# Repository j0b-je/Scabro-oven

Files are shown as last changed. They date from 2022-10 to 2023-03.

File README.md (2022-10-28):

# Scabro-oven
In this repository files relative to the oven project can be found

**The following files can be found here:**
1. The Arduino code for both the slownbox and modified pizza oven
2. The nextion interface files for both the slowbox and modified pizza oven
3. Manuels for both calibrating the thermocoupels and the oven it self(The complete oven manual will be added later on)
4. The electrical diagram of the slowbox and modified pizza oven (Will be added later on) 
5. The following 3D files:
5.1. Modified pizza oven screenholder and casement
5.2. Thermocoupels calibration cube
5.3. The Arduino Mega 2560 holder
5.4 The daughterboard holder for the thermocoupels

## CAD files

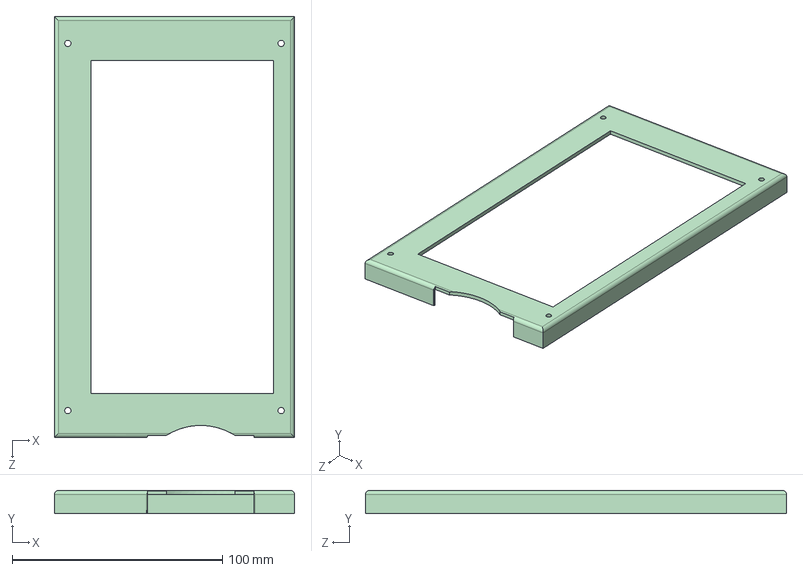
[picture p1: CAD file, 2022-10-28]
5. 3D models/.5.1 Oven screen holder and case/Top part LCD Casement.STEP
114.3 x 11.1 x 200.3 mm

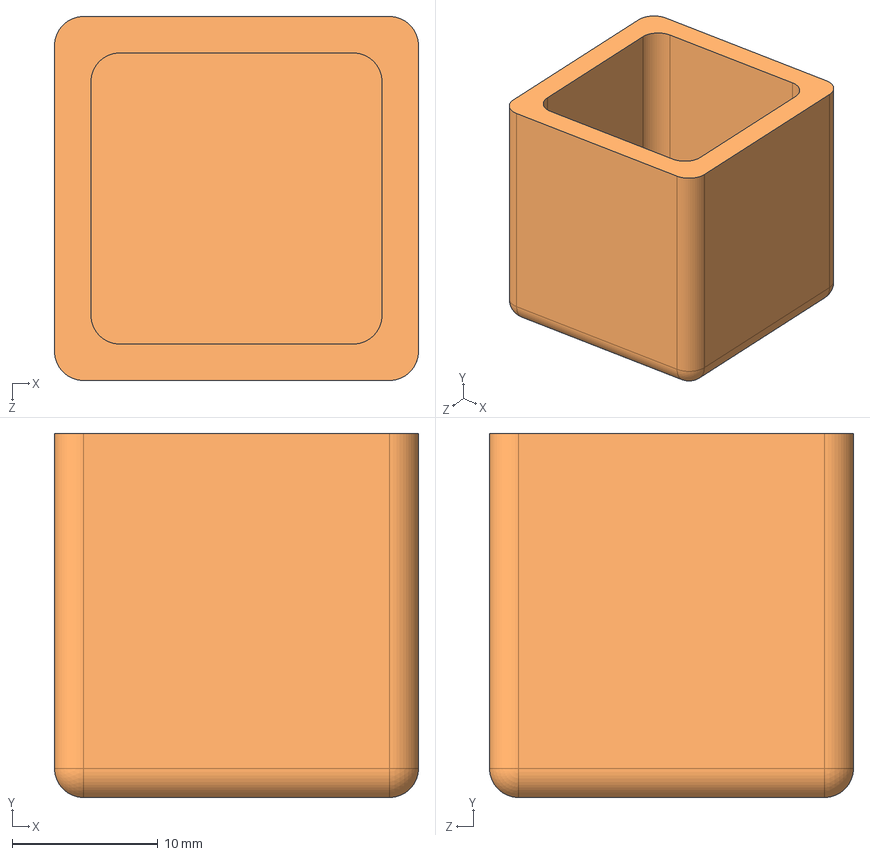
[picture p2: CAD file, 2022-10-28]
5. 3D models/5.2 Thermocouple calibration cube/Calib cube.STEP
25.0 x 25.0 x 25.0 mm

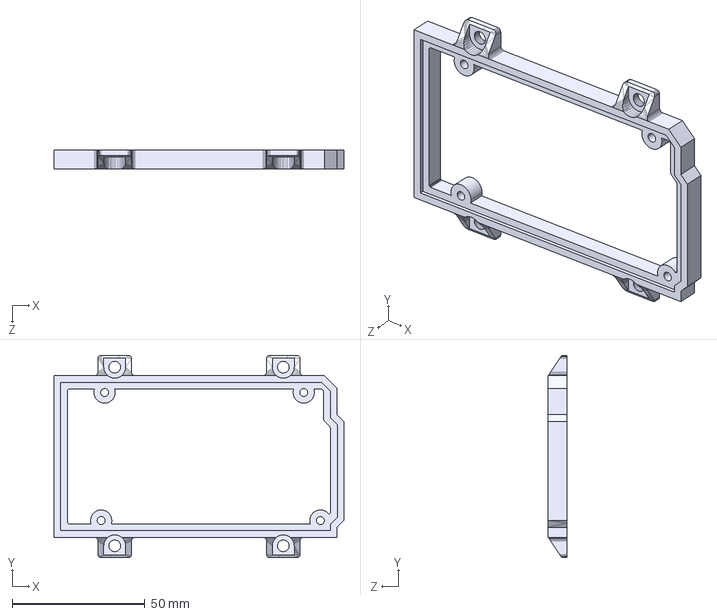
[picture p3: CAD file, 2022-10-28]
5. 3D models/5.3. Arduino Mega 2560 holder/Arduino mega 2560 holder m3.STEP
109.2 x 76.2 x 6.99 mm

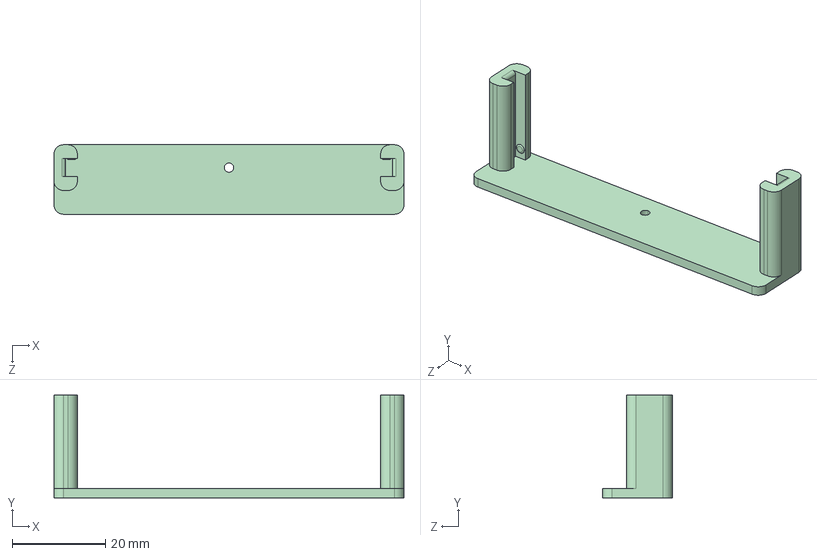
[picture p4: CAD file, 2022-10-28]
5. 3D models/5.4 Daughterboard holder for the thermocouples/Thermocouplers holder.STEP
75.0 x 22.0 x 14.9 mm

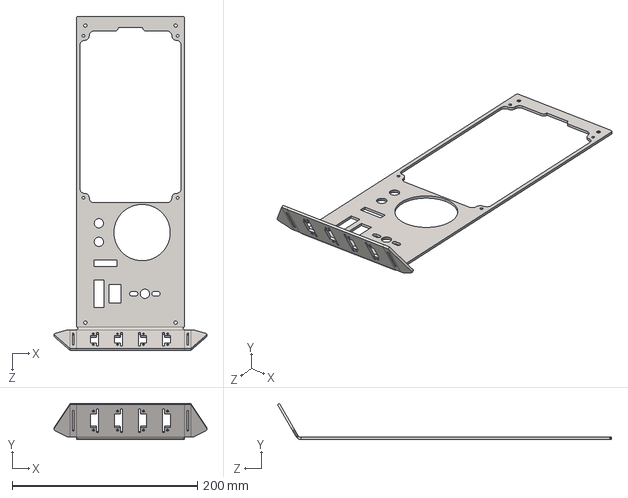
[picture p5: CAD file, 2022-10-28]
5. 3D models/.5.1 Oven screen holder and case/LCD_behuizing V2 sheet metal HandBend .STEP
165.0 x 38.9 x 360.2 mm

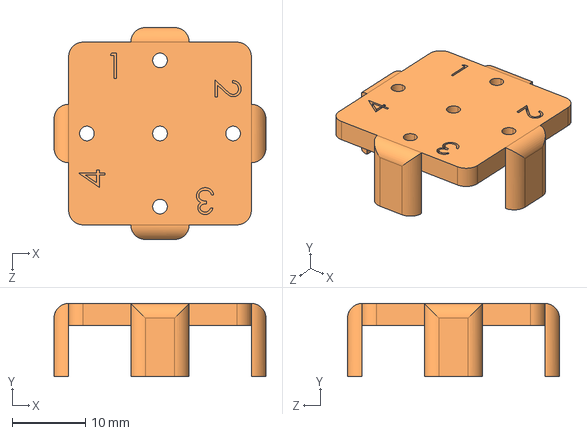
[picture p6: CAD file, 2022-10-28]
5. 3D models/5.2 Thermocouple calibration cube/Calib cube Lid.STEP
29.0 x 10.0 x 29.0 mm

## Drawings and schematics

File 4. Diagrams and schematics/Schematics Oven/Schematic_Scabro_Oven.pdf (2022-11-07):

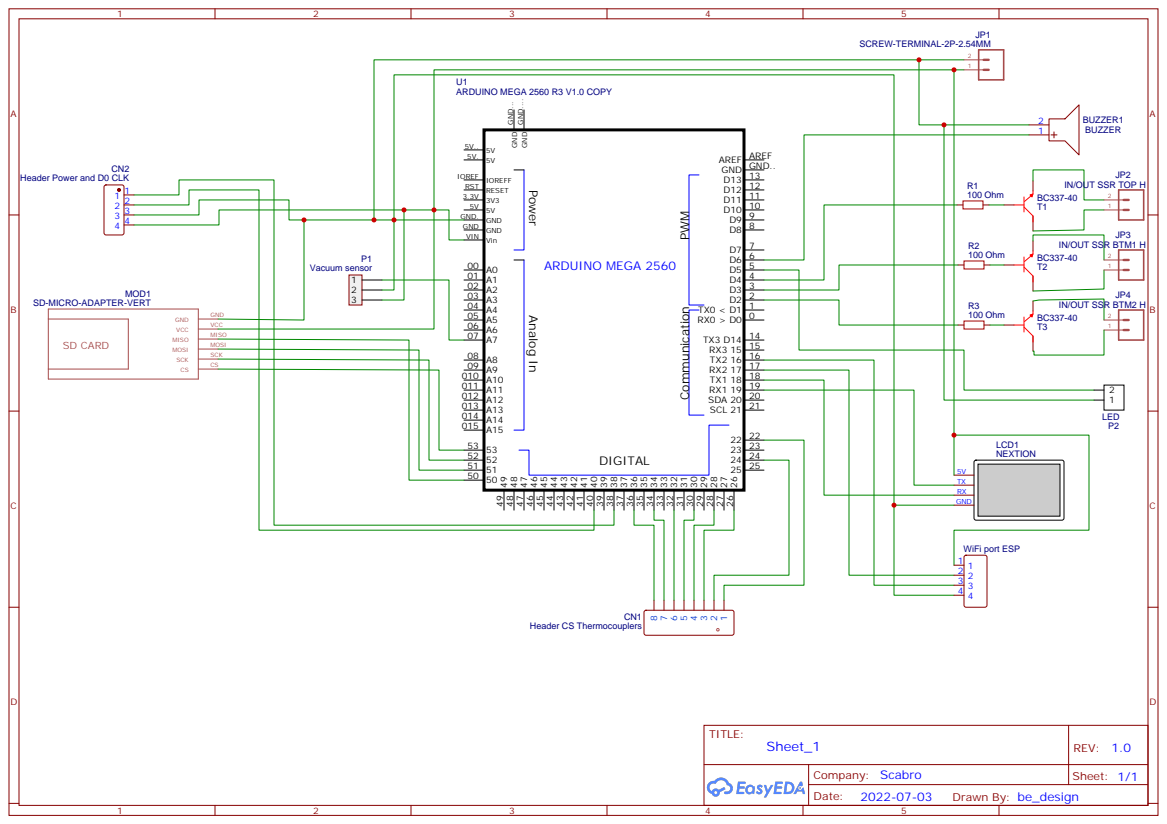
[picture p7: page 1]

Header Power and D0 CLK

SD-MICRO-ADAPTER-VERT

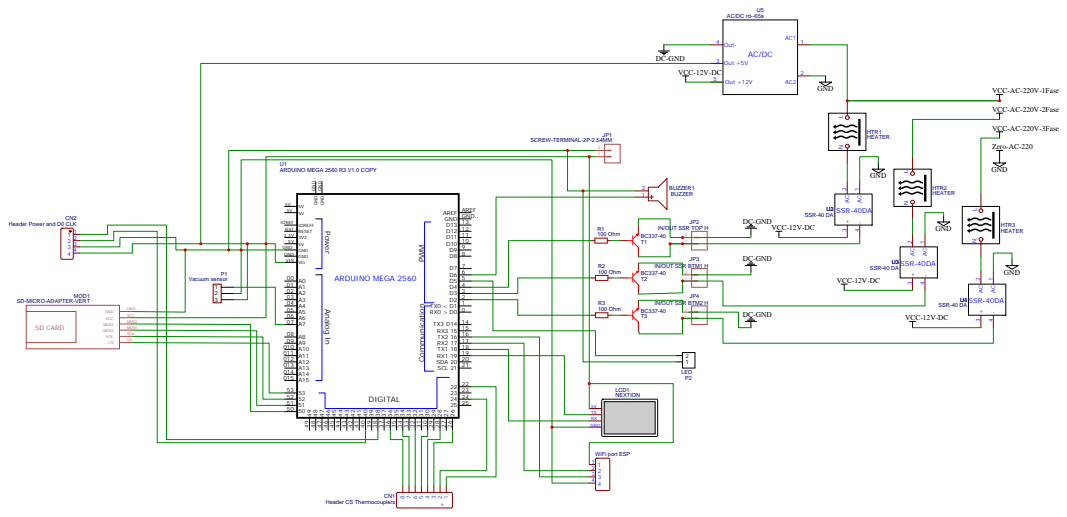
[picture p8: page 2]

Header Power and D0 CLK

SD-MICRO-ADAPTER-VERT

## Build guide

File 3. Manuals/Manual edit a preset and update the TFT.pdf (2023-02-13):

# Change/update the heat cycle presets

- First open the Nextion editor (https://nextion.tech/nextion-editor/)
- Open the HMI file
- Go to the tab on the right side of the screen, “Page”

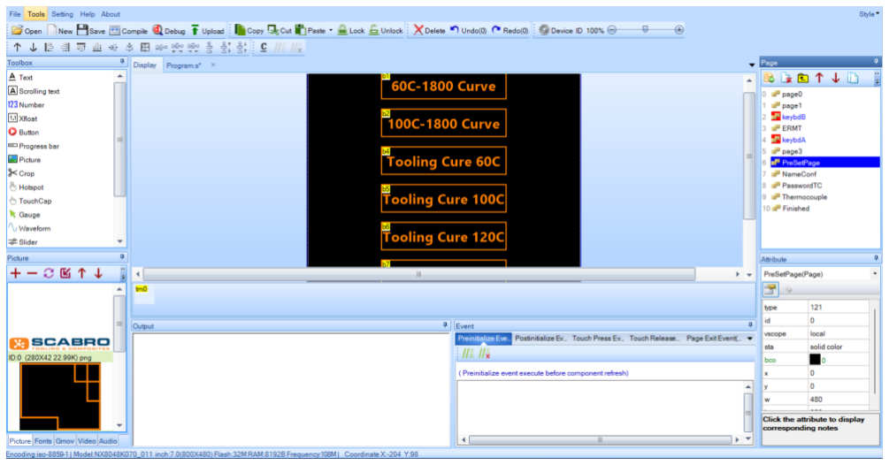
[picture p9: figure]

- Here its possible to edit a preset.

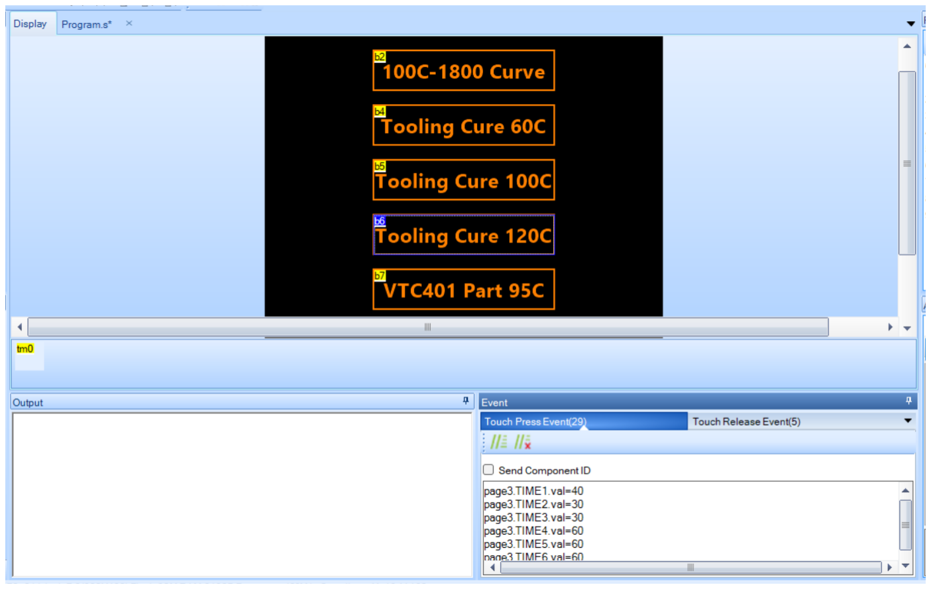
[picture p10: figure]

- In the “Touch Preset Event(X)” it’s possible to edit the time duration and temperature of each stage.

- It’s also possible to change the name of the preset.

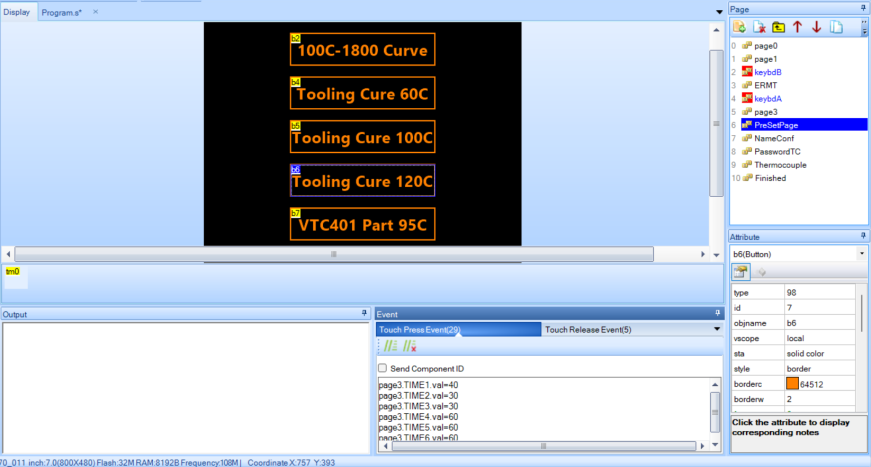
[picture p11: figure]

- Go to the Attributes tab on the right bottom corner.
- Scroll down till “txt” shows up.

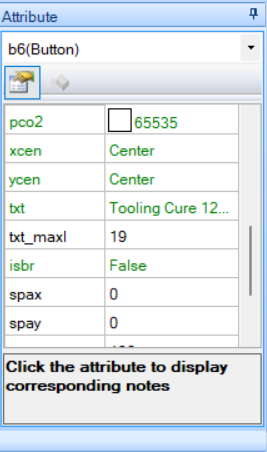
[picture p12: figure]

- By clicking on the text field it’s possible to edit the preset name.
- Under the “txt” field there is also “txt_maxl” this is the maximum amount of characters allowed. This can also be changed by simply increasing or decreasing the number.
- If the name is too long the following will pop up.

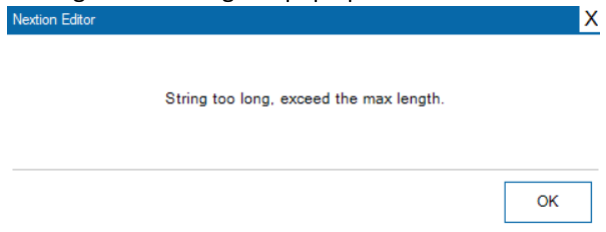
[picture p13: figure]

# Upload the new HMI file to the Nextion

screen.

Materials needed:

- An empty microSD card with less memory than 32GB
- The updated HMI file
- A microSD to USB A adaptor or SD card adaptor, this depends on the computer being used.

Updating the Nextion screen

- Press the compile button to check if there is no error, found on the top toolbar
- If no errors occur go to “File” => “TFT file output” and select the desired folder to save the file to.
- Put the .tft file on the microSD card.
- Remove the microSD card with ONLY the .tft file on it from the computer.
- Turn of the Nextion screen, set the oven switch to 0/off.
- Put the microSD card into the side of the Nextion screen

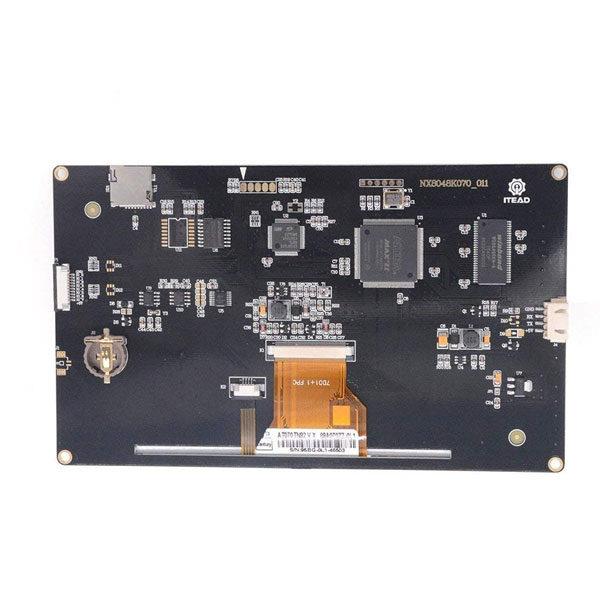
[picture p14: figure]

- Turn on the Nextion screen, it should start installing the new .tft file. Afterward it will start booting the new/edited program.
- After successfully installing the new .tft file turn of the screen and remove the microSD card.

Need more clarification, please use the following guides

- Nextion (https://nextion.tech/faq-items/using-nextion-microsd/)
- Youtube video (https://www.youtube.com/watch?v=6tH-azsptEo)

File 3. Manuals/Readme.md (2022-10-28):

**The complete oven manual will be added later on**

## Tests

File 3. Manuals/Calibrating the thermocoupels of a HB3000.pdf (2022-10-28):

Calibrating the thermocouples of a HB3000

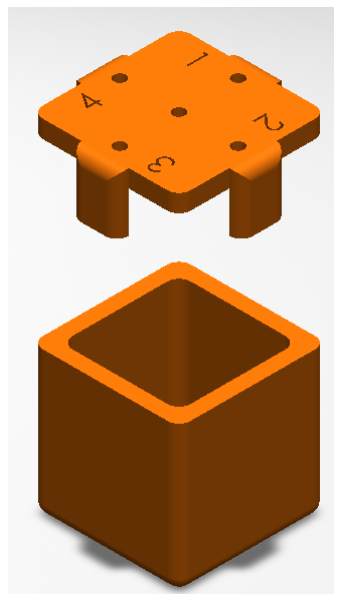
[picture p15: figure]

To calibrate the 4 thermocouple, found on the outside of the furnace successfully the following items are needed:
- Calibration Cube
- 20 CC of water
- A Thermocouple datalogger
- A thermocouple

Start by opening the calibration cube, do this with utmost care because the legs will break if not.
Next, insert the corresponding thermocouples into the holes, followed by the datalogger thermocouple which goes into the centre hole. Make sure that each thermocouple has at least a centimetre of wire on the underside of the lid.
And with the wire all properly seated, the water can be added to the cube.
Let the thermocouple get to the temperature of the water, this will take about a minute. In the meantime, go to the settings page on the screen. Then go to Thermocouples.
First tap “Enter” without anything in text field, this is an extra safety measure. Now the PIN code can be inserted “4123” followed by hitting “Enter” again. Upon opening the screen the value may all be empty, please wait patiently for the oven to represent the values . If this process takes over a minute and still doesn’t show the offset values, use the “Refresh” button.
When the values are loaded in use the “+ “ and “-“ to adjust each of the offsets to the value upon the datalogger. If the thermocouples are adjusted to the corresponding offsets, use the “Back” button to store these and go back to settings page.

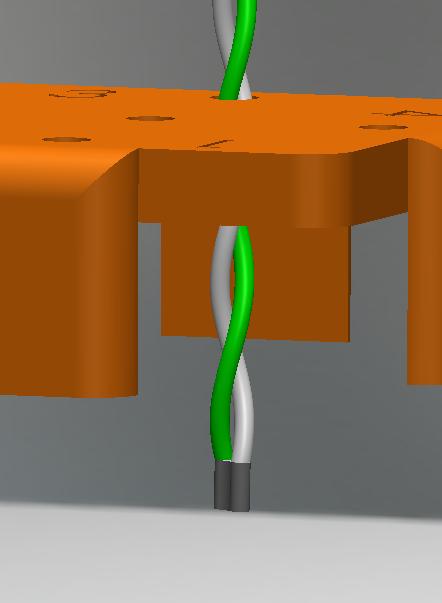
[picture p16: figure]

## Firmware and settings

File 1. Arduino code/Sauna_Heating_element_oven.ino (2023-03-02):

#include "max6675.h"
#include <AutoPID.h>
#include <SPI.h>
#include <SD.h>
#include <EEPROM.h>

#define NextionSerial Serial1
#define DebugSerial Serial

#define OUTPUT_PINHTR1 2
#define OUTPUT_PINHTR2 3
#define OUTPUT_PINHTR3 4

// Eeprom Addresses
// 6 adresses for the thermcouple on the cart 
int TCA1 = 0;
int TCA2 = 2;
int TCA3 = 4;
int TCA4 = 6;
int TCA5 = 8;
int TCA6 = 10;

//Time left intergers
int MAXTemp = 0;
int RampTime = 0;// Will be set after each Speed set
int TotalRampTime = 0;
int TimeSum = 0;

bool TTS = false;

bool Temprecieved = false;
bool Timerecieved = false;

bool FileWithName = false;
bool FileNameCheck = false;

bool TimeLock = false;
bool Dataprocessing = false;
bool ThermoProces = false;

bool SendData = false;

int thermoDO = 38;
int thermoCLK = 40;

//SD card Reader
bool check = false;
File myFile; // create file for writing data to SD Card shield.
const int chipSelect = 4;
char NameType[8];

//thermocouples
int thermoCS = 22;
int thermoCS1 = 24;
int thermoCS2 = 26;
int thermoCS3 = 28;
int thermoCS4 = 30;
int thermoCS5 = 32;
int thermoCS6 = 34;
int thermoCS7 = 36;

//Read Nextion command temp and time
int ReconW = 4;
int FileName = 3;
int TotalChar = 0;

int SetTemp = 0;
unsigned long Time = 0;
int TempHeatUpState = 0;

//Time setting, multiplier
int Minutes = 1;
int MultiplierTime = Minutes * 60;

String readString; //crucial for the decoding of the nextion data
String Name = ""; // string used to save the name of a product, used for the SD card datalog

//time intervals
int T1 = 0;
int T2 = 0;
int T3 = 0;
int T4 = 0;
int T5 = 0;
int T6 = 0;
int T7 = 0;
int T8 = 0;
int T9 = 0;
int T10 = 0;
int T11 = 0;
int T12 = 0;
int T13 = 0;
int T14 = 0;


//Temp intervals
int Temp1 = 0;
int Temp2 = 0;
int Temp3 = 0;
int Temp4 = 0;
int Temp5 = 0;
int Temp6 = 0;
int Temp7 = 0;
int Temp8 = 0;
int Temp9 = 0;
int Temp10 = 0;
int Temp11 = 0;
int Temp12 = 0;
int Temp13 = 0;
int Temp14 = 0;

String CSF;
String NTSF;
String TLF;

//Boolean
boolean TEMPR = false;
boolean TIMR = false;

//Speed setting
int SpeedSet = 1;

//RunningState
int RunningState = 0;
int ThermoCheck = 0;
int Currentstate = 0;

//Delta Time for waiting time heater
unsigned long deltaTime = 0;
unsigned long WriteSDDelta = 0;
unsigned long SendTemp = 0;
unsigned long UpdateThermo = 0;

unsigned long ToTimeLeft = 0;

//Time Left Function
int TimeLeftRun = 0;

MAX6675 thermocouple(thermoCLK, thermoCS, thermoDO);
MAX6675 thermocouple1(thermoCLK, thermoCS1, thermoDO);
MAX6675 thermocouple2(thermoCLK, thermoCS2, thermoDO);
MAX6675 thermocouple3(thermoCLK, thermoCS3, thermoDO);
MAX6675 thermocouple4(thermoCLK, thermoCS4, thermoDO);
MAX6675 thermocouple5(thermoCLK, thermoCS5, thermoDO);
MAX6675 thermocouple6(thermoCLK, thermoCS6, thermoDO);
MAX6675 thermocouple7(thermoCLK, thermoCS7, thermoDO);

const int RunningAverageCount = 8;
float RunningAverageBuffer[RunningAverageCount];
int NextRunningAverage;

// Thermocouple Calibration
int ThermoVal1 = 0;
int ThermoVal2 = 0;
int ThermoVal3 = 0;
int ThermoVal4 = 0;
int ThermoVal5 = 0;
int ThermoVal6 = 0;

#define KP 1.3
#define KI 0.2// was 0,3
#define KD 1

double temperature = 20;
double outputVal = 10;
double bangOn = 6;
double bangOff = 1;
double Setpoint = 0;

//thermocouples corrections
double ThermoCorrection = -7;
double ThermoCorrection1 = -12;

float ThermoCorrection2 = 0;
float ThermoCorrection3 = 0;
float ThermoCorrection4 = 0;
float ThermoCorrection5 = 0;
float ThermoCorrection6 = 0;
float ThermoCorrection7 = 0;

float outputMin = 0;
float outputMax = 80;

//Time left
long TL = 0;

int TimeaddC = 0;
int TAC = 0;

//State Nextion
int NTS = 0;
int CS = 0;

AutoPID myPID(&temperature, &Setpoint, &outputVal, outputMin, outputMax , KP, KI, KD);

String b;

void sendCmd(String cmd)
{
  NextionSerial.print(cmd);
  NextionSerial.write("\xFF\xFF\xFF");
}

void setup()
{

  analogWrite(OUTPUT_PINHTR1, 0);
  analogWrite(OUTPUT_PINHTR2, 0);
  analogWrite(OUTPUT_PINHTR3, 0);

  //Start serial ports
  DebugSerial.begin(9600);
  NextionSerial.begin(115200);

  // Load Thermocouple Offsets form EEPROM including negative values
  ThermoVal1 = (int8_t)EEPROM.read(TCA1);
  ThermoVal2 = (int8_t)EEPROM.read(TCA2);
  ThermoVal3 = (int8_t)EEPROM.read(TCA3);
  ThermoVal4 = (int8_t)EEPROM.read(TCA4);
  ThermoVal5 = (int8_t)EEPROM.read(TCA5);
  ThermoVal6 = (int8_t)EEPROM.read(TCA6);

  ThermoCorrection2 = ThermoVal1 * 0.25;
  ThermoCorrection3 = ThermoVal2 * 0.25;
  ThermoCorrection4 = ThermoVal3 * 0.25;
  ThermoCorrection5 = ThermoVal4 * 0.25;
  ThermoCorrection6 = ThermoVal5 * 0.25;
  ThermoCorrection7 = ThermoVal6 * 0.25;

  DebugSerial.println("OffSet form EEPROM for Thermocouple 2: ");
  DebugSerial.println(ThermoVal1);
  DebugSerial.println(ThermoCorrection2);
  DebugSerial.println("OffSet form EEPROM for Thermocouple 3: ");
  DebugSerial.println(ThermoVal2);
  DebugSerial.println(ThermoCorrection3);
  DebugSerial.println("OffSet form EEPROM for Thermocouple 4: ");
  DebugSerial.println(ThermoVal3);
  DebugSerial.println(ThermoCorrection4);
  DebugSerial.println("OffSet form EEPROM for Thermocouple 5: ");
  DebugSerial.println(ThermoVal4);
  DebugSerial.println(ThermoCorrection5);
  DebugSerial.println("OffSet form EEPROM for Thermocouple 6: ");
  DebugSerial.println(ThermoVal5);
  DebugSerial.println(ThermoCorrection6);
  DebugSerial.println("OffSet form EEPROM for Thermocouple 7: ");
  DebugSerial.println(ThermoVal6);
  DebugSerial.println(ThermoCorrection7);

  //Setup PID Bang Bang
  myPID.setBangBang(bangOn, bangOff);
  //set PID update interval to 250ms
  myPID.setTimeStep(250);

  pinMode(53, OUTPUT); //To check if the micro SD is installed

  DebugSerial.print("Initializing SD card...");

  while (!NextionSerial)
  {
    DebugSerial.println("Waiting on Nextion Screen");
  }

  sendCmd("ArduinoV.txt = \"Blue Mosque\"");
  DebugSerial.println("Sending start up to Nextion Screen");
  delay(500);
  sendCmd("Trigger.val=1");
  sendCmd(""); // clear the buffer
  sendCmd("LiveTemp.txt=\"Initializing\"");
  sendCmd(""); // clear the buffer
  delay(100);

  DebugSerial.println("Awaiting Command of the Nextion Screen or DebugSerial");

  //Nextion recieve data Temp and Time
  TotalChar = ReconW + FileName;
  if (SD.begin())
  {
    DebugSerial.println("SD card is ready to use.");
    sendCmd("page1.SDcardState.txt=\"SD card istalled\"");
  }
  else
  {
    DebugSerial.println("SD card initialization failed");
    sendCmd("page1.SDcardState.txt = \"No SD card istalled\"");
    FileNameCheck = true;
  }

}
void loop()
{
  unsigned long currentMillis = millis();//Start Timer

  String mytext;
  String myvalue;
  String TempvalueAVR;
  String Tempvalue;
  String Tempvalue1;
  String Tempvalue2;
  String Tempvalue3;
  String Tempvalue4;
  String Tempvalue5;
  String Tempvalue6;
  String Tempvalue7;
  String Tempvalue8;

  String Tempval2;
  String Tempval3;
  String Tempval4;
  String Tempval5;
  String Tempval6;
  String Tempval7;

  String TL;
  String NTS;
  String CS;
  String message;
  String Processstate;

  // Thermocouple offset
  String TempOffSet1;
  String TempOffSet2;
  String TempOffSet3;
  String TempOffSet4;
  String TempOffSet5;
  String TempOffSet6;

  String OffSetN1;
  String OffSetN2;
  String OffSetN3;
  String OffSetN4;
  String OffSetN5;
  String OffSetN6;

  String THC2;
  String THC3;
  String THC4;
  String THC5;
  String THC6;
  String THC7;

  if (NextionSerial.available() > 0) {

    if (Dataprocessing == false) {
      DebugSerial.print("Dataproccesing state is: ");
      DebugSerial.println(Dataprocessing);
      DebugSerial.print("FileNameCheck state is: ");
      DebugSerial.println(FileNameCheck);
    }
    /*  DebugSerial.println("OffSet form EEPROM for Thermocouples: ");
      DebugSerial.println(ThermoCorrection4);
      DebugSerial.println(ThermoCorrection5);
      DebugSerial.println(ThermoCorrection6);
      DebugSerial.println(ThermoCorrection7); */

    DebugSerial.println("Incoming Data form nextion: ");
    DebugSerial.println(readString);

    if (Dataprocessing == true && ThermoProces == false) {
      sendCmd("t16.txt=\"Processing Data\"");
    }

    char c = NextionSerial.read();  //gets one byte from serial buffer

    if (c == '.') {
      if ('Z') {
        DebugSerial.println("Start Thermocouple Calibration process");
        ThermoProces = true;
        DebugSerial.print("Thermoproces state: ");
        DebugSerial.println(ThermoProces);
      }
    }

    if (c == '$') {
      String Trash = readString;
      DebugSerial.print("The recieved Trash: ");
      DebugSerial.println(Trash);
      Trash = "";

      //if (NextionSerial.available() == 0)//

      DebugSerial.println("Nextion Serial Buffer is empty");
      sendCmd("SendTime.val=1");
      sendCmd("t16.txt=\"Recieved Data\"");
      Dataprocessing = true;

      readString += c; //makes the string readString
    }

    if (c == '!') {
      String Trash = readString;
      DebugSerial.print("The recieved Trash: ");
      DebugSerial.println(Trash);
      Trash = "";
      readString = ""; //clears variable for new input
    }

    if (c == 'x') {
      DebugSerial.println("No File Name has been given");
      FileNameCheck = true;
      //Dataprocessing = false;
      //sendCmd("StopSender.val=0");
      readString = ""; //clears variable for new input
    }

    if (c == '>') { //Not using fro the new communication, used for hand shake methode -> Force data all the time
      DebugSerial.println("Recieved Nexttion Data request");
      SendData = true;
      readString = ""; //clears variable for new input
    }

    if (c == '(') {
      FileWithName = false;
      DebugSerial.print("The up comming Run doesn't require a file name ");
    }

    if (c == ')') {
      FileWithName = true;
      DebugSerial.print("The up comming Run requires a File Name: ");
      DebugSerial.print(FileWithName);
    }

    if (c == '@') {
      sendCmd("StopSender.val=0"); //Send to Nextion the running state
      DebugSerial.println("A Stop command has been isued");
      sendCmd("RunningState.txt=\"Stop\""); //Send to Nextion the running state

      readString = ""; //clears variable for new input
      if (check == true) {
        myFile.println("Programm Has been stopped");
        myFile.close(); // if There is a file open it will close it
        readString = ""; //clears variable for new input
        check = false;
      }
      sendCmd("t16.txt=\" \"");
      TempHeatUpState = 15; //Stop command
    }

    if (c == ',') {
      Dataprocessing = true;
      while (readString.length() > 1) {
        DebugSerial.print("The Following Data will be processed: ");
        DebugSerial.println(readString); //prints string to serial port out
        int n = readString.toInt();  //convert readString into a number
        DebugSerial.print("Writing Recieved data: ");
        DebugSerial.println(n);
        if (TimeLock == false); {
          if (readString.indexOf('a') > 0) T1 = n;
          if (readString.indexOf('b') > 0) T2 = n;
          if (readString.indexOf('c') > 0) T3 = n;
          if (readString.indexOf('d') > 0) T4 = n;
          if (readString.indexOf('e') > 0) T5 = n;
          if (readString.indexOf('f') > 0) T6 = n;
          if (readString.indexOf('g') > 0) T7 = n;
          if (readString.indexOf('h') > 0) T8 = n;
          if (readString.indexOf('i') > 0) T9 = n;
          if (readString.indexOf('j') > 0) T10 = n;
          if (readString.indexOf('k') > 0) T11 = n;
          if (readString.indexOf('l') > 0) T12 = n;
          if (readString.indexOf('m') > 0) T13 = n;
          if (readString.indexOf('n') > 0) T14 = n;
          if (readString.indexOf('o') > 0) {
            Timerecieved = true;
            sendCmd("SendT.val=1");
            sendCmd("SendTime.val=0");
            TimeLock = false;
          }
        }
        if (readString.indexOf('A') > 0) Temp1 = n;
        if (readString.indexOf('B') > 0) Temp2 = n;
        if (readString.indexOf('C') > 0) Temp3 = n;
        if (readString.indexOf('D') > 0) Temp4 = n;
        if (readString.indexOf('E') > 0) Temp5 = n;
        if (readString.indexOf('F') > 0) Temp6 = n;
        if (readString.indexOf('G') > 0) Temp7 = n;
        if (readString.indexOf('H') > 0) Temp8 = n;
        if (readString.indexOf('I') > 0) Temp9 = n;
        if (readString.indexOf('J') > 0) Temp10 = n;
        if (readString.indexOf('K') > 0) Temp11 = n;
        if (readString.indexOf('L') > 0) Temp12 = n;
        if (readString.indexOf('M') > 0) Temp13 = n;
        if (readString.indexOf('N') > 0) Temp14 = n;
        if (readString.indexOf('O') > 0) {
          Temprecieved = true;
          sendCmd("vis b5,1");
          sendCmd("t16.txt=\" \"");
          Dataprocessing = false;
          sendCmd("StopSend.val=0");
        }

        if (readString.indexOf(':') > 0) {
          SpeedSet = n;
          DebugSerial.print("SpeedSet: ");
          DebugSerial.println(SpeedSet);
          Dataprocessing = false;
        }

        if (readString.indexOf('#') > 0 && FileWithName == true) {
          if (readString.indexOf('#')) Name = readString;
          DebugSerial.print("The recieved name is: ");
          DebugSerial.println(Name);
          int LastIndex = Name.length() - 1;
          Name.remove(LastIndex);
          Name.concat(".TXT");
          DebugSerial.println(Name);

          Name.toCharArray(NameType, Name.length() + 1);
          if (SD.exists(Name)) {// Checking if The Name of the File is already occupied
            sendCmd("page NameConf"); // Opens error page on Nextion
            DebugSerial.println("File name exists.");
            FileNameCheck = false;
          }

          else {
            DebugSerial.println("File name doesn't exist.");
            DebugSerial.println(NameType);
            myFile = SD.open(Name, FILE_WRITE);
            myFile.print("This file originatie from this file name: ");
            myFile.println(Name);

            FileNameCheck = true;
            check = true;

            readString = ""; //clears variable for new input
          }

          Dataprocessing = false;
        }
        readString = ""; //clears variable for new input
      }
    }
    else {
      readString += c; //makes the string readString
    }
  }

  while (ThermoProces == true && Dataprocessing == false) {

    char c = NextionSerial.read();

    //TempOffSet1 = int(thermocouple4.readCelsius() - ThermoCorrection4);

    TempOffSet1 = int(thermocouple2.readCelsius() + ThermoCorrection2);
    TempOffSet2 = int(thermocouple3.readCelsius() + ThermoCorrection3);
    TempOffSet3 = int(thermocouple4.readCelsius() + ThermoCorrection4);
    TempOffSet4 = int(thermocouple5.readCelsius() + ThermoCorrection5);
    TempOffSet5 = int(thermocouple6.readCelsius() + ThermoCorrection6);
    TempOffSet6 = int(thermocouple7.readCelsius() + ThermoCorrection7);

    THC2 = ThermoVal1 * 0.25;
    THC3 = ThermoVal2 * 0.25;
    THC4 = ThermoVal3 * 0.25;
    THC5 = ThermoVal4 * 0.25;
    THC6 = ThermoVal5 * 0.25;
    THC7 = ThermoVal6 * 0.25;
    
    OffSetN1 = "\"" + THC2 + "\"";
    OffSetN2 = "\"" + THC3 + "\"";
    OffSetN3 = "\"" + THC4 + "\"";
    OffSetN4 = "\"" + THC5 + "\"";
    OffSetN5 = "\"" + THC6 + "\"";
    OffSetN6 = "\"" + THC7 + "\"";

    // current temperature with compensation

    sendCmd("OffSet1.txt=" + OffSetN1);
    sendCmd("OffSet2.txt=" + OffSetN2);
    sendCmd("OffSet3.txt=" + OffSetN3);
    sendCmd("OffSet4.txt=" + OffSetN4);
    sendCmd("OffSet5.txt=" + OffSetN5);
    sendCmd("OffSet6.txt=" + OffSetN6);
    
    sendCmd("THCC1.val=" + TempOffSet1);
    sendCmd("THCC2.val=" + TempOffSet2);
    sendCmd("THCC3.val=" + TempOffSet3);
    sendCmd("THCC4.val=" + TempOffSet4);
    sendCmd("THCC5.val=" + TempOffSet5);
    sendCmd("THCC6.val=" + TempOffSet6);

    if (c == 'A') {
      ThermoVal1 ++;
      DebugSerial.println("Increasing First Thermocouple");
      ThermoCorrection2 = ThermoVal1 * 0.25;
      sendCmd("OffSet1.txt=" + OffSetN1);
    }
    if (c == 'a') {
      ThermoVal1 --;
      DebugSerial.println("Decreasing First Thermocouple");
      ThermoCorrection2 = ThermoVal1 * 0.25;
      sendCmd("OffSet1.txt=" + OffSetN1);
    }
    if (c == 'B') {
      ThermoVal2 ++;
      DebugSerial.println("Increasing Second Thermocouple");
      ThermoCorrection3 = ThermoVal2 * 0.25;
      sendCmd("OffSet2.txt=" + OffSetN2);
    }
    if (c == 'b') {
      ThermoVal2 --;
      DebugSerial.println("Decreasing Second Thermocouple");
      ThermoCorrection3 = ThermoVal2 * 0.25;
      sendCmd("OffSet2.txt=" + OffSetN2);
    }
    if (c == 'C') {
      ThermoVal3 ++;
      DebugSerial.println("Increasing Third Thermocouple");
      ThermoCorrection4 = ThermoVal3 * 0.25;
      sendCmd("OffSet3.txt=" + OffSetN3);
    }
    if (c == 'c') {
      ThermoVal3 --;
      DebugSerial.println("Decreasing Third Thermocouple");
      ThermoCorrection4 = ThermoVal3 * 0.25;
      sendCmd("OffSet3.txt=" + OffSetN3);
    }
    if (c == 'D') {
      ThermoVal4 ++;
      DebugSerial.println("Increasing Fourth Thermocouple");
      ThermoCorrection5 = ThermoVal4 * 0.25;
      sendCmd("OffSet4.txt=" + OffSetN4);
    }
    if (c == 'd') {
      ThermoVal4 --;
      DebugSerial.println("Decreasing Fourth Thermocouple");
      ThermoCorrection5 = ThermoVal4 * 0.25;
      sendCmd("OffSet4.txt=" + OffSetN4);
    }
    
    if (c == 'E') {
      ThermoVal5 ++;
      DebugSerial.println("Increasing Fifth Thermocouple");
      ThermoCorrection6 = ThermoVal5 * 0.25;
      sendCmd("OffSet5.txt=" + OffSetN5);
    }
    if (c == 'e') {
      ThermoVal5 --;
      DebugSerial.println("Decreasing Fifth Thermocouple");
      ThermoCorrection6 = ThermoVal5 * 0.25;
      sendCmd("OffSet5.txt=" + OffSetN5);
    }

     if (c == 'F') {
      ThermoVal6 ++;
      DebugSerial.println("Increasing Sixth Thermocouple");
      ThermoCorrection7 = ThermoVal6 * 0.25;
      sendCmd("OffSet6.txt=" + OffSetN6);
    }
    if (c == 'f') {
      ThermoVal6 --;
      DebugSerial.println("Decreasing Sixth Thermocouple");
      ThermoCorrection7 = ThermoVal6 * 0.25;
      sendCmd("OffSet6.txt=" + OffSetN6);
    }
      
    // Back button
    if (c == 'X') {
      DebugSerial.println("Back Button has been pressed");

      EEPROM.update(TCA1, ThermoVal1);
      EEPROM.update(TCA2, ThermoVal2);
      EEPROM.update(TCA3, ThermoVal3);
      EEPROM.update(TCA4, ThermoVal4);
      EEPROM.update(TCA5, ThermoVal5);
      EEPROM.update(TCA6, ThermoVal6);

      DebugSerial.println("Data Has been Saved in the EEPROM");
      ThermoProces = false;
      return;
    }

    readString = ""; //clears variable for new input
  }

  if (Dataprocessing == false && ThermoProces == false) {

    if (Timerecieved == true && Temprecieved == true) {

      DebugSerial.println("Data has been recieved");
      DebugSerial.println(T1);
      DebugSerial.println(T2);
      DebugSerial.println(T3);
      DebugSerial.println(T4);
      DebugSerial.println(T5);
      DebugSerial.println(T6);
      DebugSerial.println(T7);
      DebugSerial.println(T8);
      DebugSerial.println(T9);
      DebugSerial.println(T10);
      DebugSerial.println(T11);
      DebugSerial.println(T12);
      DebugSerial.println(T13);
      DebugSerial.println(T14);
      DebugSerial.println("Recieved data temperature: ");
      DebugSerial.println(Temp1);
      DebugSerial.println(Temp2);
      DebugSerial.println(Temp3);
      DebugSerial.println(Temp4);
      DebugSerial.println(Temp5);
      DebugSerial.println(Temp6);
      DebugSerial.println(Temp7);
      DebugSerial.println(Temp8);
      DebugSerial.println(Temp9);
      DebugSerial.println(Temp10);
      DebugSerial.println(Temp11);
      DebugSerial.println(Temp12);
      DebugSerial.println(Temp13);
      DebugSerial.println(Temp14);

      TIMR = true;
      TEMPR = true;

      Timerecieved = false;
      Temprecieved = false;

      if (check == true && FileNameCheck == true) {
        DebugSerial.println("Writing Run setting to Micro SD card");
        myFile.println("This run has been excudeted with the following setting: ");
        myFile.print("Temperature");
        myFile.print(":");
        myFile.println("Time");

        myFile.print(Temp1);
        myFile.print(":");
        myFile.println(T1);
        myFile.print(Temp2);
        myFile.print(":");
        myFile.println(T2);
        myFile.print(Temp3);
        myFile.print(":");
        myFile.println(T3);
        myFile.print(Temp4);
        myFile.print(":");
        myFile.println(T4);
        myFile.print(Temp5);
        myFile.print(":");
        myFile.println(T5);
        myFile.print(Temp6);
        myFile.print(":");
        myFile.println(T6);
        myFile.print(Temp7);
        myFile.print(":");
        myFile.println(T7);
        myFile.print(Temp8);
        myFile.print(":");
        myFile.println(T8);
        myFile.print(Temp9);
        myFile.print(":");
        myFile.println(T9);
        myFile.print(Temp10);
        myFile.print(":");
        myFile.println(T10);
        myFile.print(Temp11);
        myFile.print(":");
        myFile.println(T11);
        myFile.print(Temp12);
        myFile.print(":");
        myFile.println(T12);
        myFile.print(Temp13);
        myFile.print(":");
        myFile.println(T13);
        myFile.print(Temp14);
        myFile.print(":");
        myFile.println(T14);

      }
    }

    float RawTemperature = ((thermocouple.readCelsius()+ ThermoCorrection + thermocouple1.readCelsius()+ ThermoCorrection1) / 2);

    RunningAverageBuffer[NextRunningAverage++] = RawTemperature;
    if (NextRunningAverage >= RunningAverageCount)
    {
      NextRunningAverage = 0;
    }
    float RunningAverageTemperature = 0;
    for (int i = 0; i < RunningAverageCount; ++i)
    {
      RunningAverageTemperature += RunningAverageBuffer[i];
    }
    RunningAverageTemperature /= RunningAverageCount;
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

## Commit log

2022-10-28 Create 1. Arduino code
2022-10-28 Update and rename 1. Arduino code to 1. Arduino code.gitkeep
2022-10-28 Added Raw Slowbox code
    **Note**
    This arduino file still contains some less than desirable code, this will change over the course of the upcoming month.
2022-10-28 Added manual thermocouple calibration
2022-10-28 Added Screen files
    [LCD_behuizing V2 sheet metal HandBend .STEP, Top part LCD behuizing.STEP]
2022-10-28 Added Thermocouple calibratrion cube
    [Calib cube Lid.STEP, Calib cube.STEP]
2022-10-28 Added Arduino Mega 2560 Holder
    [Arduino mega 2560 holder m3.STEP]
2022-10-28 Added Correct Top LCD part
    [Top part LCD Casement.STEP]
2022-10-28 Added Thermocouple daughterboard holder
    [Thermocouplers holder.STEP]
2022-10-31 Updated Oven code
    Change the Heating programming because of the new thermocouples locations.
2022-11-07 Uploaded Oven Schematics
    The PDF file contains both the layout of the PCB and of the entire system
2022-11-07 Update Oven com with Nextion
    Added to the data transfer of the both temperature and time a closing character, instead of rellying on the fact that the last data point of the set will be greater than 0.
2022-12-17 Added the Arduino code for the blue big oven
2022-12-17 Added the Nextion file for the oven power by a sauna heater
2023-02-13 Update Sauna_Heating_element_oven.ino
    Changed maximum amount of power per speed setting; slow, normal, fast
    line 1080 till 1102
2023-02-14 Minor change
    Added an additional variable to calculate, ThermoTotalAvg, to calculate the average of the 6 product temperatures.
